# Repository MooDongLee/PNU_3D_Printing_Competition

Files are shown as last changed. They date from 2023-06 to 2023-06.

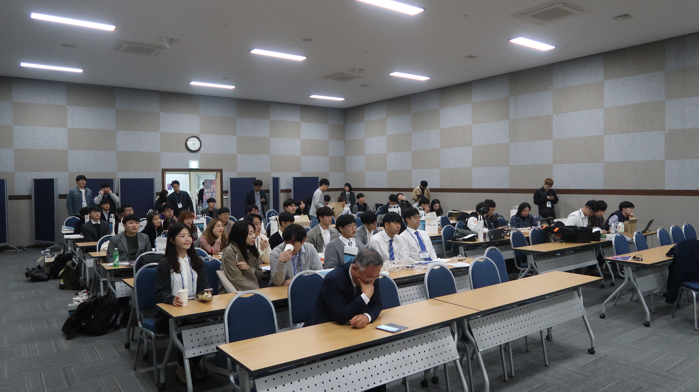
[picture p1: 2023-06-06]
Pictures/1.JPG

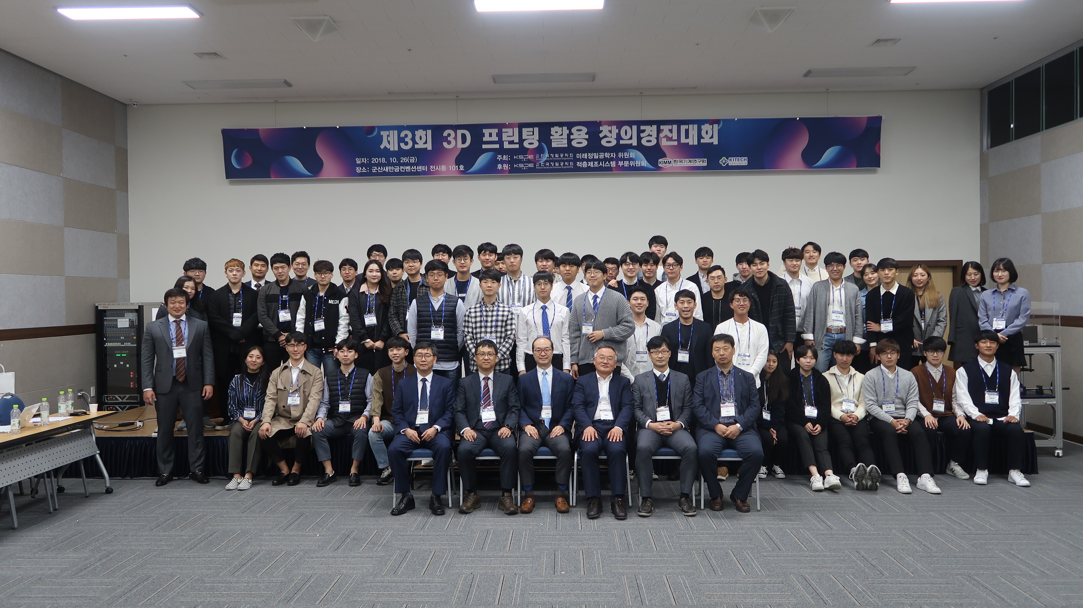
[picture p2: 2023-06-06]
Pictures/2.JPG

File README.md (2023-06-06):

# PNU_3D_Printing_Competition
- 기간 : 2018.05.01 ~ 2018.10.26 (제3회 3D 프린팅 활용 창의 경진대회)
- Project 내용: 공모전 발표 내역_Team Rocks.pptx 참고
- 발표 영상 : https://www.youtube.com/watch?v=B-IDxinnWpM
- 사용한 기자재: 3D Printing
- 상세 설명
1) 한국정밀공학회에서 주관한 '제3회 3D 프린팅 활용 창의 경진대회'에 참가하여 최소한의 자중으로 최대한의 하중을 버티는 교량 구조를 설계 및 제작. 107kg의 수직하중 지지.

<p align="center">
  
  
  
  
  
  
  
  
  
  
  
  
  
  </p>

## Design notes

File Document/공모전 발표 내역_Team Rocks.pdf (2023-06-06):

## 제 3 회 3D Printing 활용 창의 경진 대회 Presentation

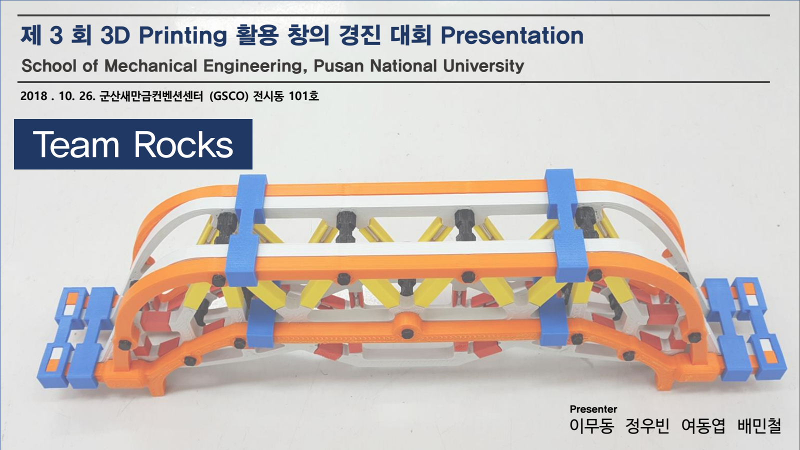
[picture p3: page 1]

School of Mechanical Engineering, Pusan National University

Presenter

2018 . 10. 26. 군산새만금컨벤션센터 (GSCO) 전시동 101호

### 이무동 정우빈 여동엽 배민철

# Team Rocks

## Contents

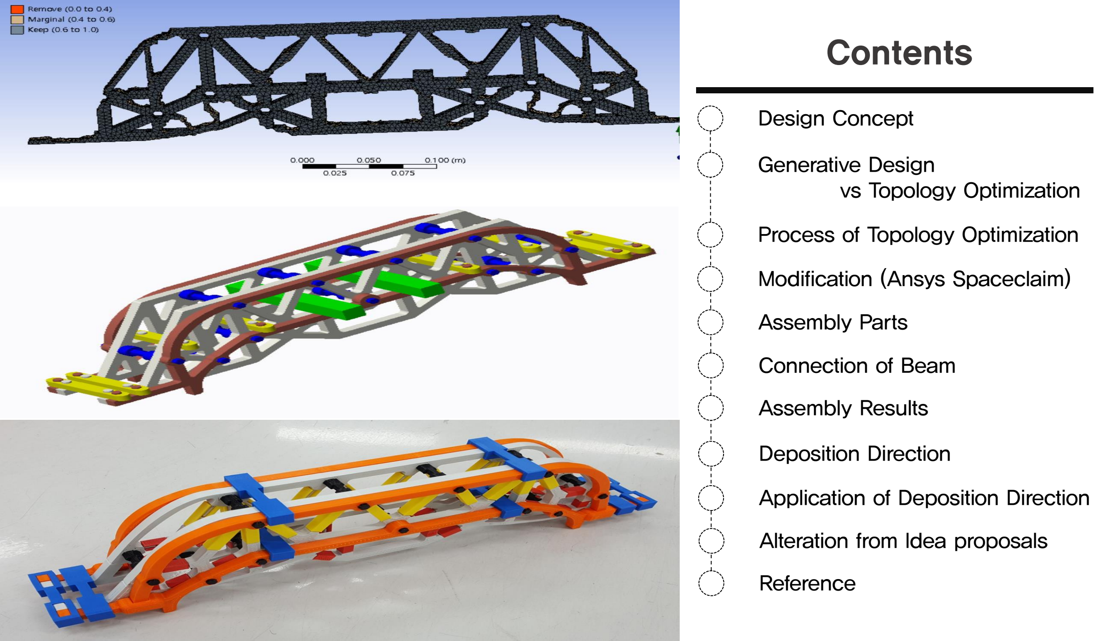
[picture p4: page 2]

Design Concept

Generative Design
vs Topology Optimization

Reference

Assembly Parts

Connection of Beam

Process of Topology Optimization

Deposition Direction

Application of Deposition Direction

Modification (Ansys Spaceclaim)

Alteration from Idea proposals

Assembly Results

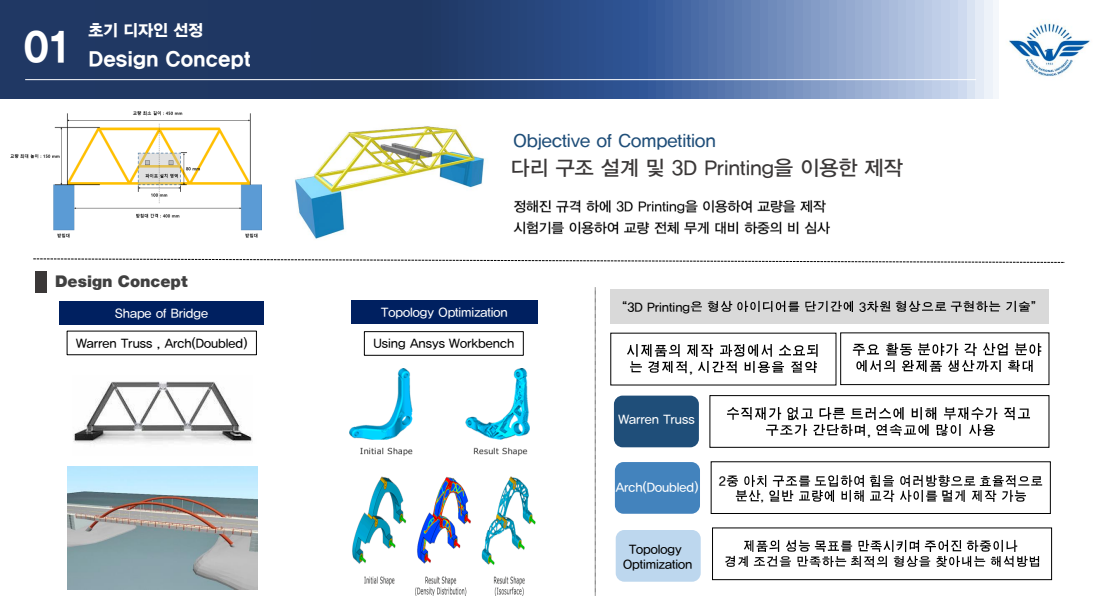
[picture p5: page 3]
Design Concept; “3D Printing; Shape of Bridge; Topology Optimization; Warren Truss; Arch(Doubled)

초기 디자인 선정 01 Design Concept

Objective of Competition
다리 구조 설계 및 3D Printing을 이용한 제작

Warren Truss , Arch(Doubled)

Using Ansys Workbench

Generative Design

생성적 디자인 vs 위상 최적화 02 Generative Design vs Topology Optimization

Topology Optimization

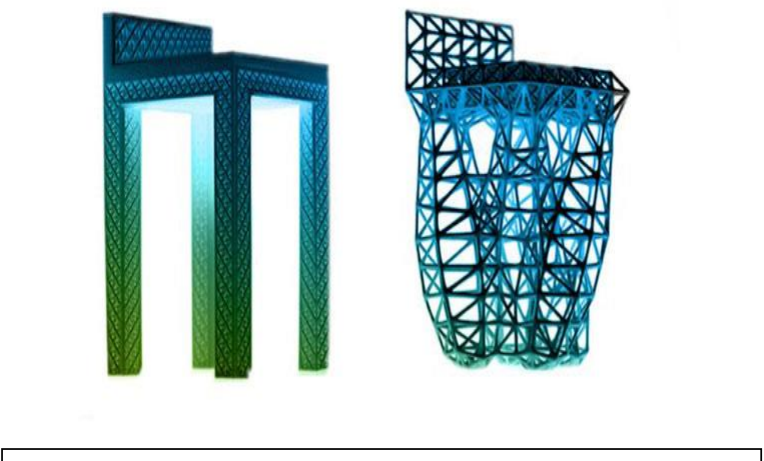
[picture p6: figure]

- AI
- ,
- Machine Learning

▪

▪

▪

Comparison

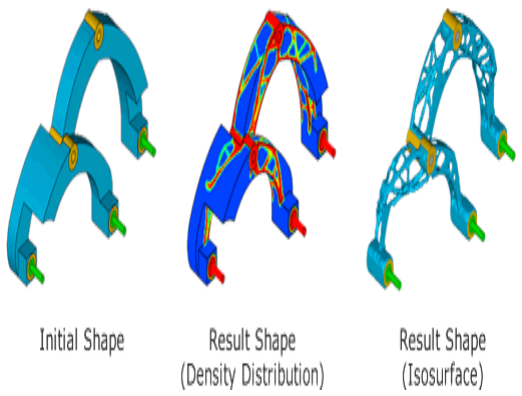
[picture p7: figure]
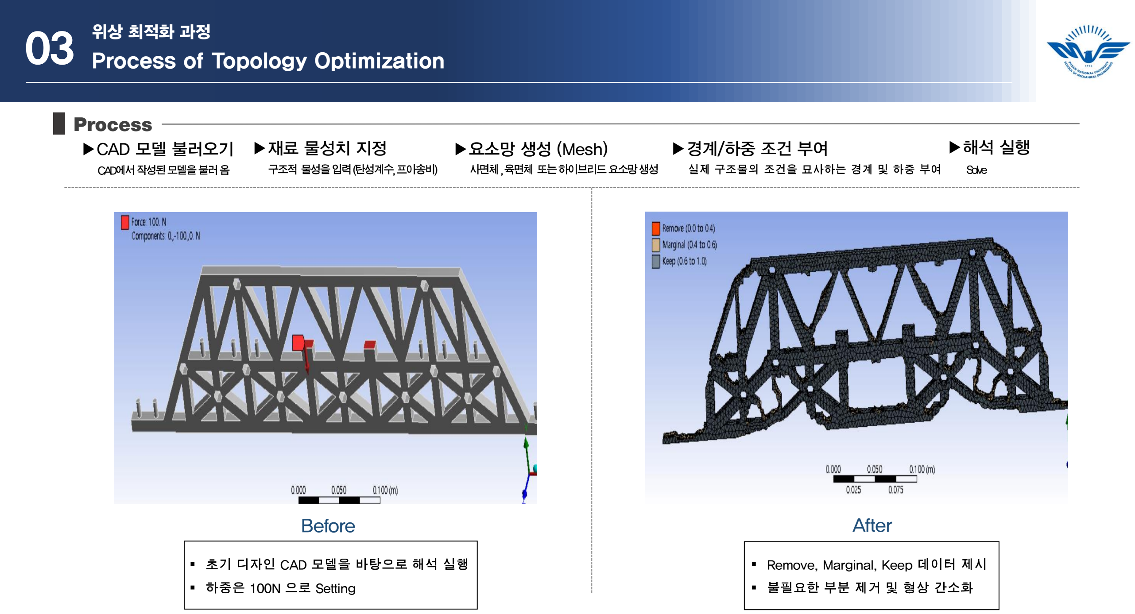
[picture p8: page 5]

▶요소망 생성 (Mesh) | ▶경계/하중 조건 부여

,

▶재료 물성치 지정

( | , | )

▶해석 실행

Solve

위상 최적화 과정 03 Process of Topology Optimization

▶CAD 모델 불러오기

CAD

- CAD
- | 100N | Setting
- Remove, Marginal, Keep

▪

Before | After

Process

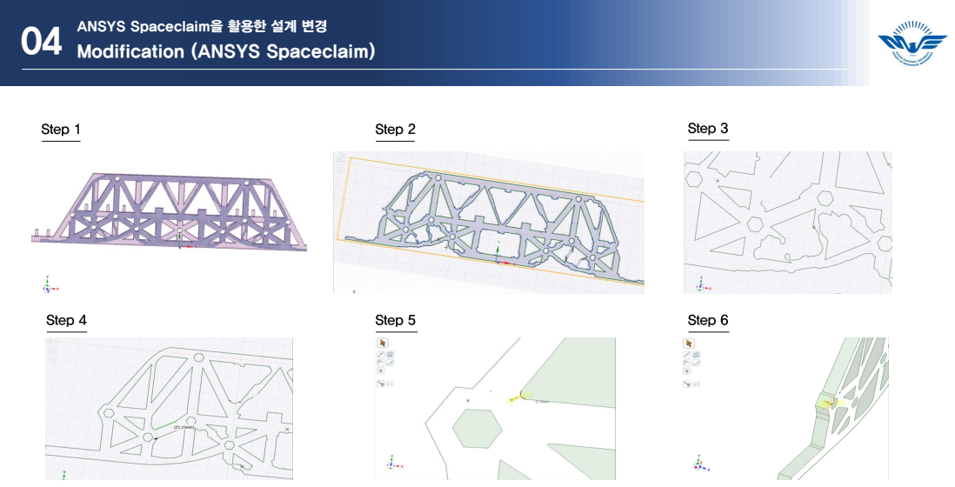
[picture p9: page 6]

ANSYS Spaceclaim을 활용한 설계 변경 04 Modification (ANSYS Spaceclaim)

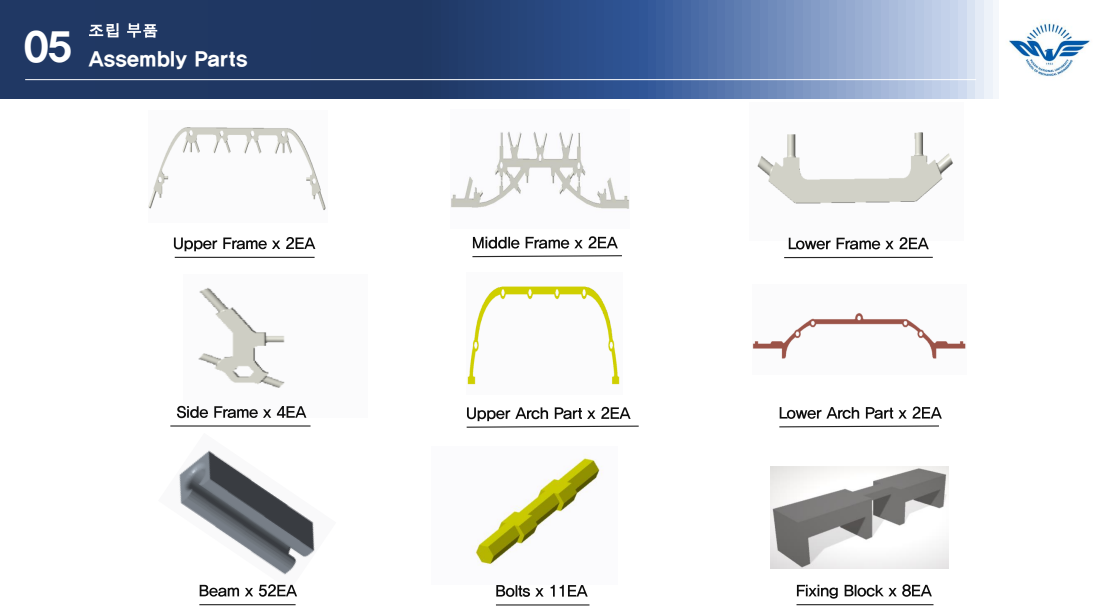
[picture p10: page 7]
05 Assembly Parts

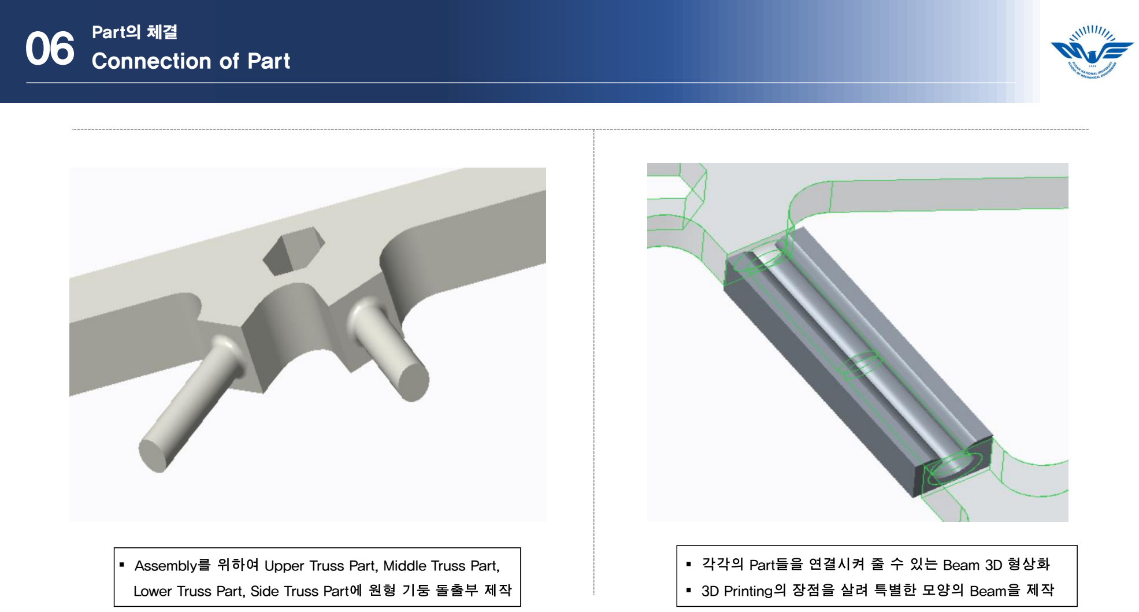
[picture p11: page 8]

Part의 체결 06 Connection of Part

- Assembly | Upper Truss Part, Middle Truss Part,

Lower Truss Part, Side Truss Part

- | Part | Beam 3D
- 3D Printing | Beam

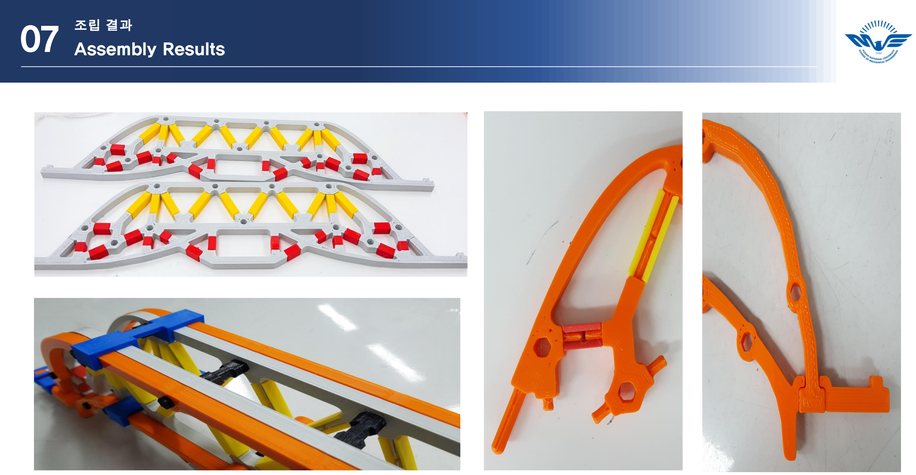
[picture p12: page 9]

07 Assembly Results

적층 방향 08 Deposition Direction

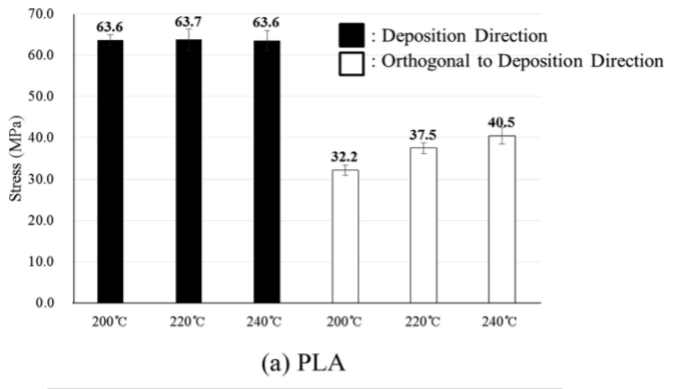
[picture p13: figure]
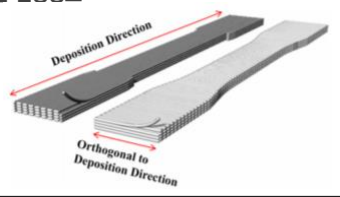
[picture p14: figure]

적층 방향에 따른 인장강도

FDM(Fused Deposition Modeling)

적층 방향(Deposition Direction) & 적층 직각 방향 (Orthogonal to Deposition Direction)

PLA(Polylactic acid)의 적층 방향에 따른 인장강도 비교

- | FDM | 3D Printing | Road
- | Road | (Deposition Direction)
| | (Orthogonal to Deposition Direction)

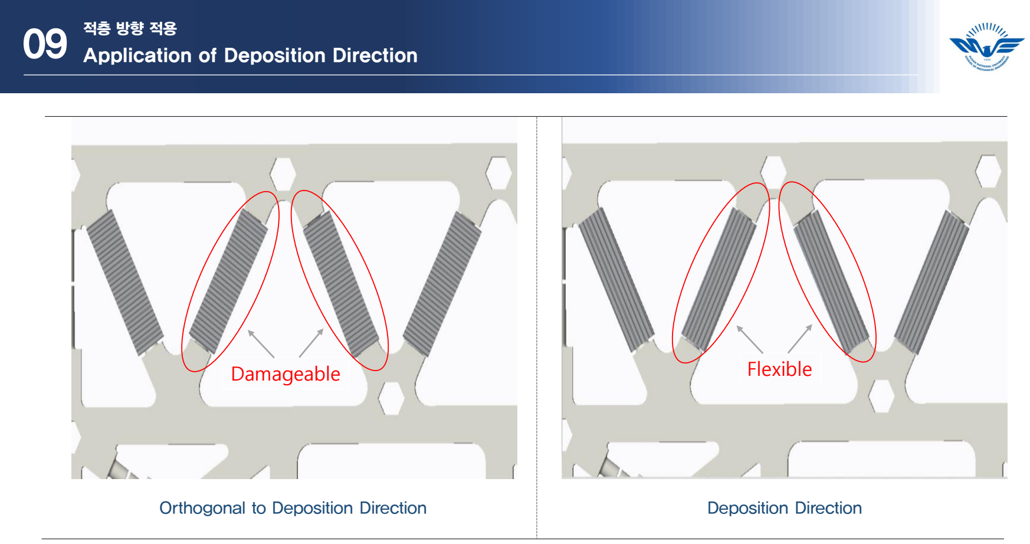
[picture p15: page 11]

적층 방향 적용 09 Application of Deposition Direction

Damageable | Flexible
Orthogonal to Deposition Direction | Deposition Direction

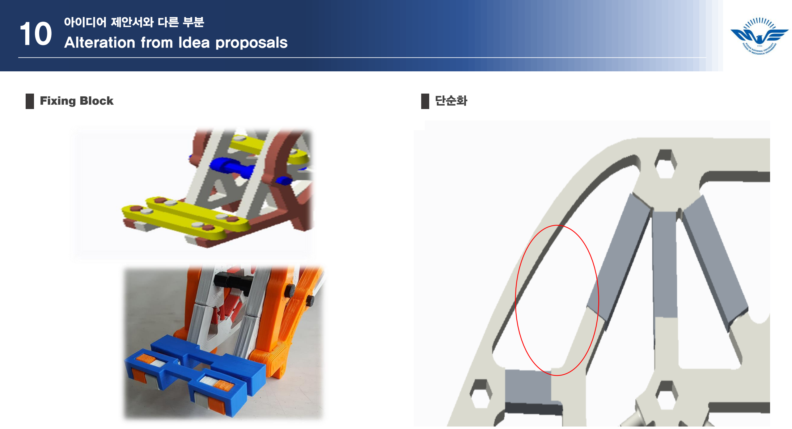
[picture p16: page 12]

아이디어 제안서와 다른 부분 10 Alteration from Idea proposals

Fixing Block | 단순화

https://bit.ly/2PtAmCp - Generative Design

https://bit.ly/2RJqaaq - Topology Optimization

https://bit.ly/2Rh1xAR - Seong-Je Park, Seoul National University of Science and Technology, "Deposition Strength of

Specimens Manufactured Using Fused Deposition Modeling Type 3D Printer" (2016)

참조 11 Reference

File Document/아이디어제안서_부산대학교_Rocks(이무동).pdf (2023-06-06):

한국정밀공학회 제 3 회 3D 프린팅 활용 창의 경진대회

### 1. 독창성 및 실용성

PLA 재질은 3D 프린터의 주요 재료로써
강도가 | 구조체 | 제작에도 | 널리
사용되므로강성이 큰 물질이므로 | 재료로
선택하였다.트러스 구조를 채택하였다. 이에
따라서 여러가지 트러스 구조 중 가장
보편적으로 쓰이는 Warren 트러스 구조를
기본으로 교량을 설계하였다. 사용하였다.
트러스 구조의 장점은 간단한 설비로 교량
가설이 가능하고 실제로 건설할 시에 부품
조달이 용이하다는 점이 있다. 이후 아치형
구조물을 추가로 트러스에 접합한다. 큰
강성을 가지는 때문에 아치는 | 타이드
아치(Tied | Arch) | 구조를 | 채택하고 | 높은
하중을 | 잘 | 견디기지지하기 | 위하여해
종로아치와 히로아치 두 가지를 조합한 2 중
아치구조로 | 결정하였다. | 그리고 | 안쪽은
Warren 트러스 구조, 바깥쪽은 2 중 아치 구조로 이루어지는데, 두개의 구조는 육각형
나사로 결합된다. 최소의 부재로 최대의
중량을 버티기 위해 위상 최적화(Topology
Optimization)와 | 생성적 | 설계(Generative
Design)를 검토하였다.
그리고 안쪽은 Warren 트러스 구조, 바깥쪽은 22 중 아치 구조로 이루어지는데, 두개의
구조는를 육각형 나사로 결합된다. 시킨다.
최소의 부재로 최대의 중량을 버티기 위해
위상 최적화(Topology Optimization)와 생성적 설계(Generative Design)를 검토하였다.

Fig. 1 Generative Design (Autodesk)(참고문헌)

생성적 | 설계는 | 가능한 | 모든 | 솔루션을

탐색하여 신속하게 설계 대안을 생성한다.
솔루션을 | 반복적으로 | 찾아가면서 | 무엇이
작동하고 | 무엇이 | 작동하지 | 않는지를
테스트하고 | 학습한다. | 설계자는 | 조건을
입력하고 | 소프트웨어는 | 인공 | 지능 | 기반
알고리즘을 | 클라우드에서 | 실행하여 | 검증
후에 선택할 수 있는 광범위한 설계 대안을
산출한다. 그러나 본 대회에서는 제한적인
길이와 | 재료를 | 사용하여 | 실제 | 교량을
제작해야 하기 때문에 이런 생성적 설계는
제한적인 길이와 재료를 사용해야 하는 본
대회의 취지와는가 맞지 않다고 판단하여 기
때문에 | 본 | 연구에서는 | 위상 | 최적화를
이용하여 최적선택하여 설계를 진행하였다.

Fig. 2 Topology Optimization (참고문헌 Quint)

사용된 부재를 최대한 줄여 비용을 절감하기
위해서 위상최적화(Topology Optimization)를 사용한다. 위상 최적화는 구조물의 위상학적
기하 형상을 주어진 조건에 가장 적합한
형태로 만드는 과정을 의미한다. 공학에서
이용하는 위상 최적화 방법은 일반적으로
주어진 영역을 유한개의 요소로 나누고, 각
요소를 채워진 요소(material)과 빈 요소(no material)로 결정하는 과정이다. 교량의
위상학적 기하 형상을 최적화하기 위해서
해석하려는 부재를 유한요소법을 사용하여
정의한 | 후, | 해석프로그램(ANSYSnsys
Workbench)을
사용한다. 그 결과에 따라 불필요한 부분을
삭제하거나 줄이고, 강화하여 3D 이미지로
변환, 이를 시각적으로 나타낸다.

## 트러스구조스와 위상최적화를 이용한 교량 설계

## Design of a Bridge Using Truss Structure and Topology Optimization

*여동엽, 배민철, 정우빈, 이무동, 안석영( 지도교수) 부산대학교 기계공학부

서식 지정함: 글꼴 색: 검정

한국정밀공학회 제 3 회 3D 프린팅 활용 창의 경진대회

### 2. 작품 상세설명

기본적인 Warren 트러스를 설계하였다.

Fig. 3 Initial Design

파이프를 삽입하여 ANSYSnsys Workbench 프로그램을 이용, 위상 최적화를 진행하였다.
100kg 의 하중이 가해진다고 가정한 후 해석을 진행한 결과, 본 그림과 같은 형태가 나왔다.

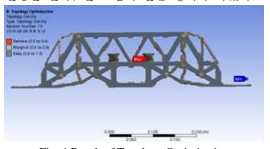
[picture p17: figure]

Fig. 4 Result of Topology Optimization

윗부분의 수직한 부재와 파이프 밑의 일부
부재가 필요 없는 부분으로 나오고 일부
부재는 좀더 얇아도 하중을 지탱하는데 무리가
없다는 해석 결과가 나왔다. 이를 토대로 다시
모델을 구축한 결과, 최종적으로 본 형태와
같은 트러스를 얻었다.

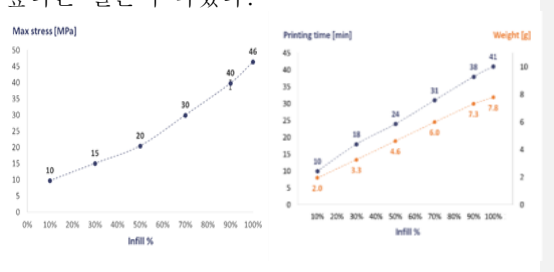
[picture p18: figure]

Fig. 5 Revised Design

트러스의 바깥쪽에 결합되는 아치의 경우
종로아치와 | 히로아치를 | 하단에서 | 결합한
형태로 | 모델링하였다. | 상단의 | 히로아치가

전반적인 트러스 전체를 떠받치며 하중을
분산시킨다면, | 히로아치는 | 직접 | 하중이
전달되는 부분을 종로아치와 하부 트러스에
전달하도록 하였다.

Fig. 6 Configuration of Arch

트러스와 아치를 모델링 한 후 나사 결합부를
체결한 다음과 같은 최종형상을 얻었다

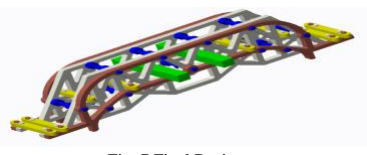
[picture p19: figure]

Fig. 7 Final Design

트러스와 아치의 모델링을 완료한 후 가장
많은 하중을 버티기 위해 3D 프린팅 부재의
적층 방향과 Infill 량을 결정하였다.

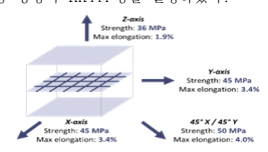
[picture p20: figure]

Fig.8 Anisotrophy (참고문헌 My3DMatter) 적층 방향의 경우 트러스의 넓은 면을
정면이라 했을 때 정면을 눕혀서 프린팅 하는
것이 세워서 프린팅 하는 것 보다 강도가
높다는 결론이 나왔다.

한국정밀공학회 제 3 회 3D 프린팅 활용 창의 경진대회

Fig.9 Maximum Stress & Weight along Infill (My3DMatter)
Infill 에 따른 최대응력, 프린팅 시간,
부재의 무게를 고려했을 때 30%의 Infill 이 가장 적합하다고 판단하였다.

### 3. 결론 및 고찰

본 | 설계에서는 | Warren | 트러스 | 구조와
경계면의 치수를 설정한 상태에서 내부의
모양을 최적화하는 방법인 위상 최적화 방법을
사용하여 기존의 교량보다 경량화 되고 많은
하중을 견딜 수 있도록 하는 데에 초점을
두었다. 이를 통하여 재료비 뿐만 아니라
제작비까지 절감 할 수 있다고 생각한다.

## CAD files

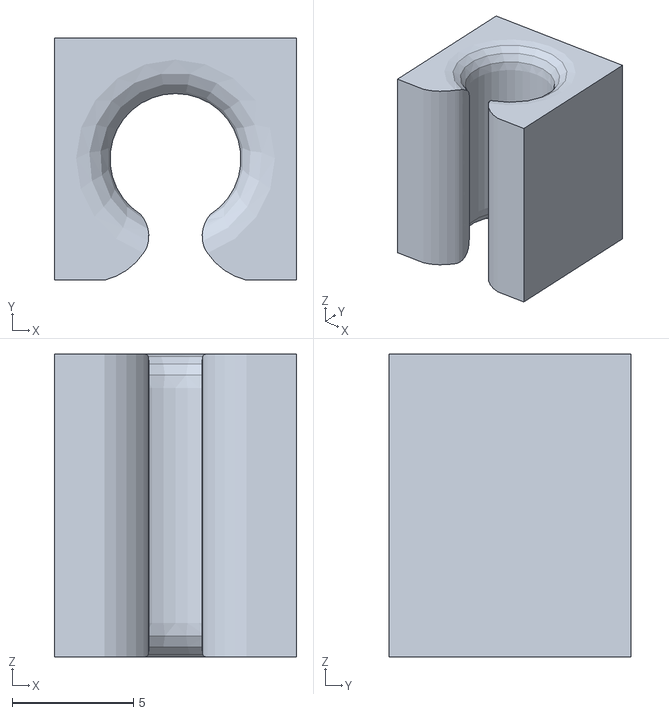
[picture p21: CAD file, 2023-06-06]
Modeling/JOINT/13.stl
10.0 x 10.0 x 12.5

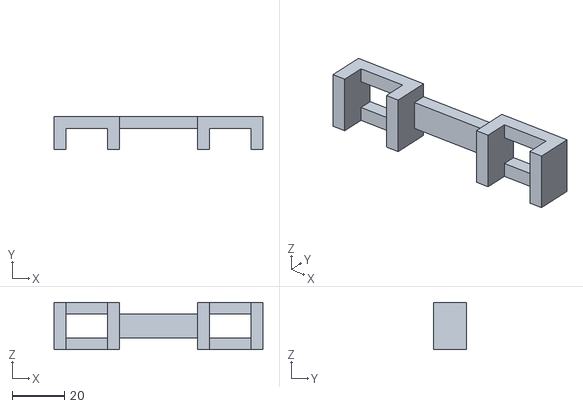
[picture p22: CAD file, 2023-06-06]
Modeling/lego2.stl
80.0 x 12.5 x 18.0

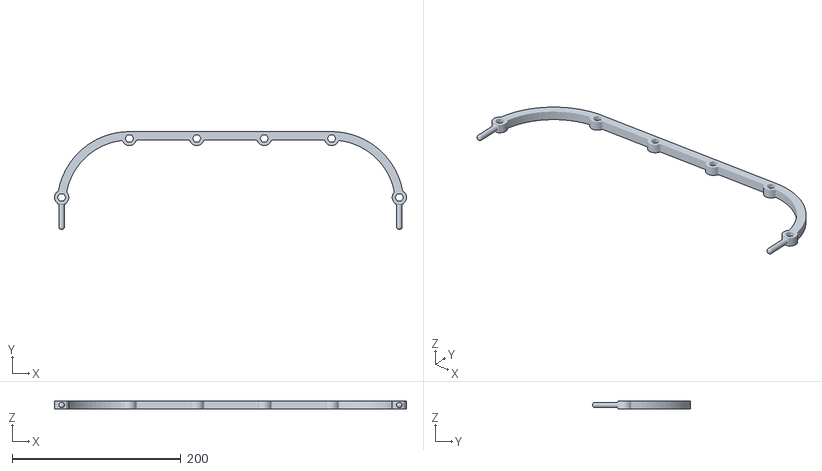
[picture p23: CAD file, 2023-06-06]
Modeling/arch_up.stl
417.7 x 115.8 x 10.0

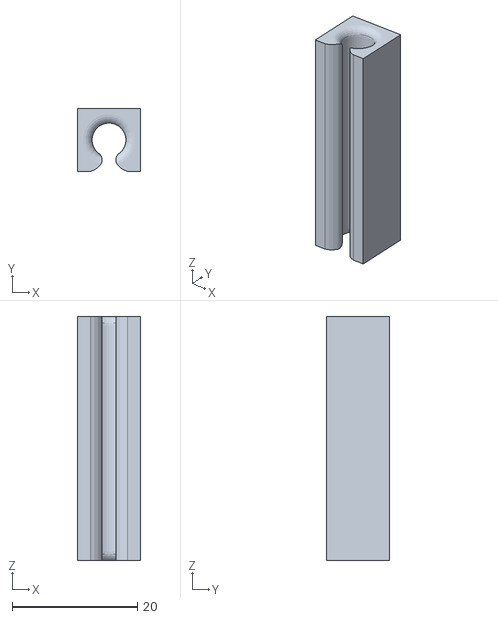
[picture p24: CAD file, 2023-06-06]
Modeling/JOINT/40.stl
10.0 x 10.0 x 39.0

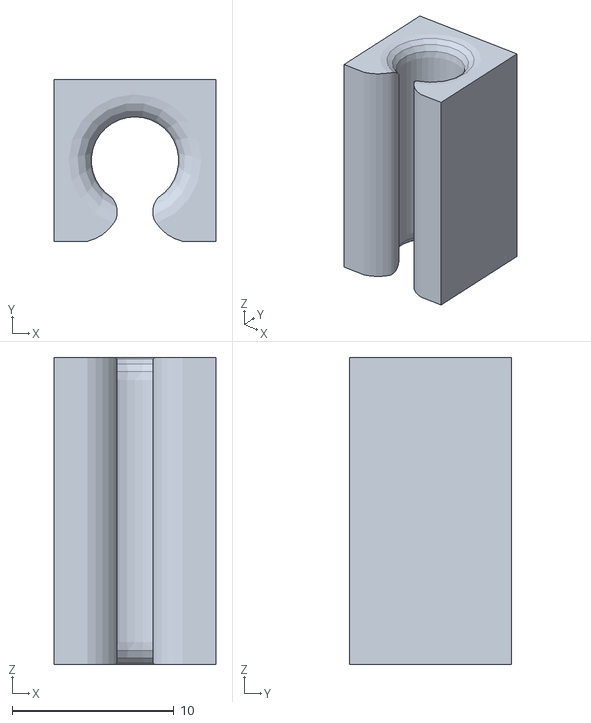
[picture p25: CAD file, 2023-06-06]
Modeling/JOINT/20.stl
10.0 x 10.0 x 19.0

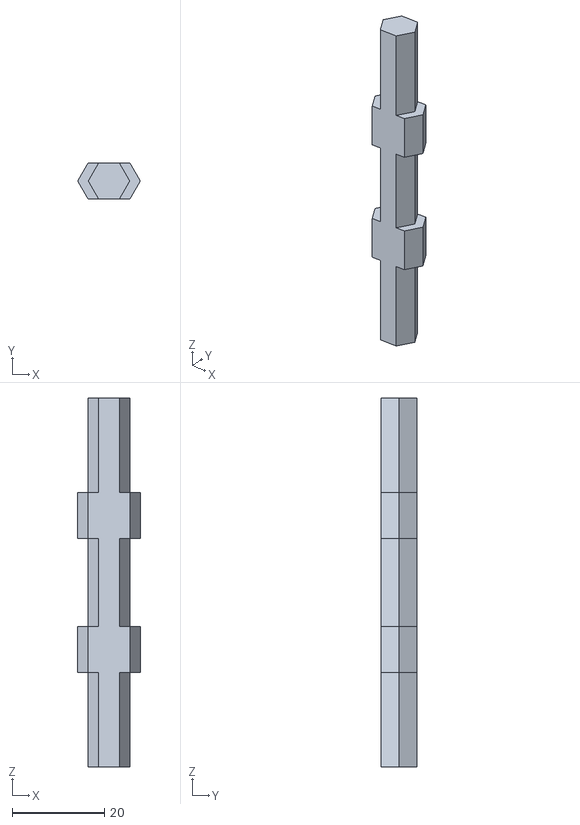
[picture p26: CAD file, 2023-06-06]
Modeling/nasa45_final.stl
13.6 x 7.79 x 80.0

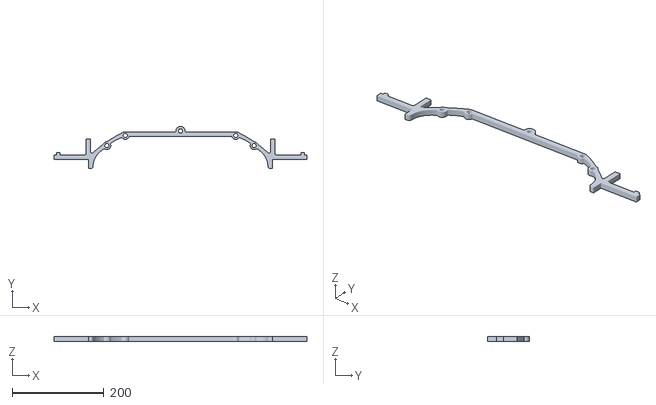
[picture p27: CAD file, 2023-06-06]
Modeling/arch_down.stl
550.0 x 92.0 x 10.0

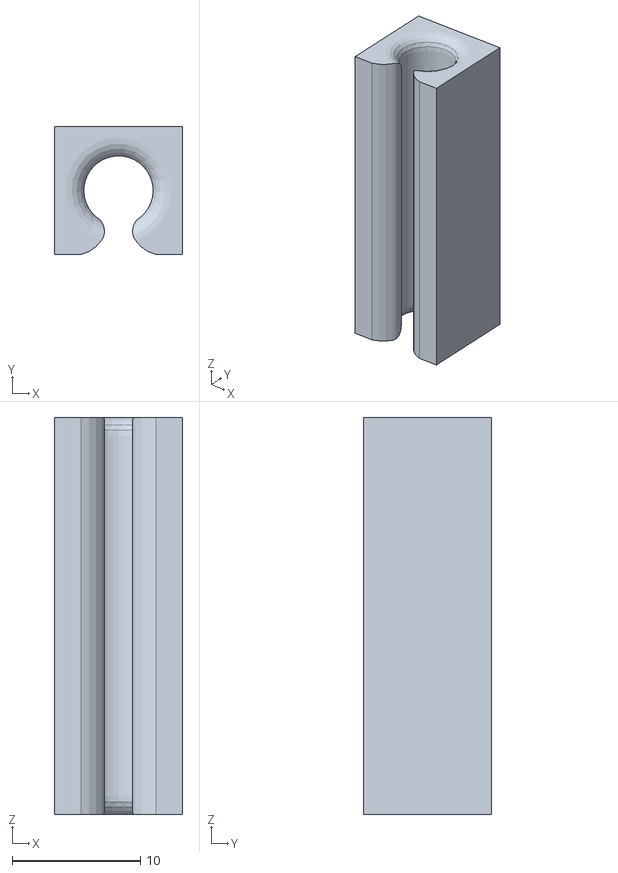
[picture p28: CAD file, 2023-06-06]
Modeling/JOINT/32.stl
10.0 x 10.0 x 31.0

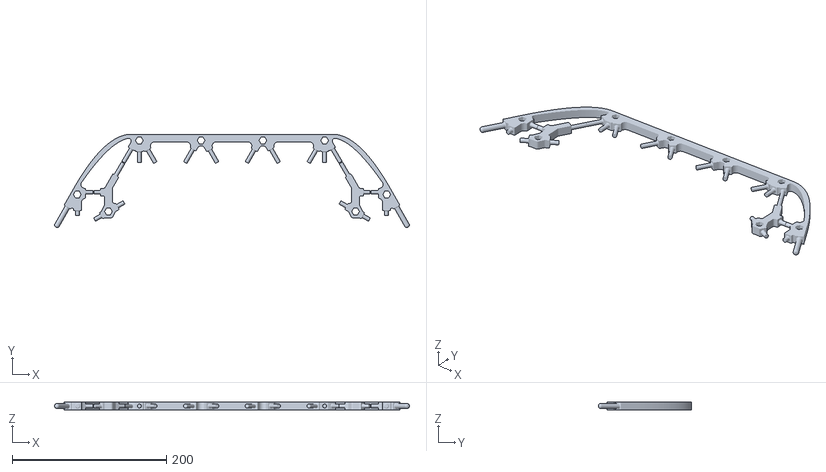
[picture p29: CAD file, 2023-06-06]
Modeling/truss_up2.stl
459.7 x 121.0 x 10.0
